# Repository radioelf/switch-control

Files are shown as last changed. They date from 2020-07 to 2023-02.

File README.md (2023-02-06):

# switch-control

switch-control/Crossover switch (Kicad Versión: 5.99.0, release build)

Interruptor, conmutador (doble), cruzamiento, controlado con un modulo ESP8266, lo estoy usando con Tasmota (https://github.com/arendst/Tasmota), con la siguiente configuración:
D2 GPIO4  Botón1in (126)
D1 GPIO5  Llave1n (82)
D6 GPIO12 Relé1 (21)
D7 GPIO13 Led1 (53)

Creative Commons License Disclaimer

UNLESS OTHERWISE MUTUALLY AGREED TO BY THE PARTIES IN WRITING, LICENSOR OFFERS THE WORK AS-IS AND MAKES NO REPRESENTATIONS OR WARRANTIES OF ANY KIND CONCERNING THE WORK, EXPRESS, IMPLIED, STATUTORY OR OTHERWISE, INCLUDING, WITHOUT LIMITATION, WARRANTIES OF TITLE, MERCHANTIBILITY, FITNESS FOR A PARTICULAR PURPOSE, NONINFRINGEMENT, OR THE ABSENCE OF LATENT OR OTHER DEFECTS, ACCURACY, OR THE PRESENCE OF ABSENCE OF ERRORS, WHETHER OR NOT DISCOVERABLE. SOME JURISDICTIONS DO NOT ALLOW THE EXCLUSION OF IMPLIED WARRANTIES, SO SUCH EXCLUSION MAY NOT APPLY TO YOU. EXCEPT TO THE EXTENT REQUIRED BY APPLICABLE LAW, IN NO EVENT WILL LICENSOR BE LIABLE TO YOU ON ANY LEGAL THEORY FOR ANY SPECIAL, INCIDENTAL, CONSEQUENTIAL, PUNITIVE OR EXEMPLARY DAMAGES ARISING OUT OF THIS LICENSE OR THE USE OF THE WORK, EVEN IF LICENSOR HAS BEEN ADVISED OF THE POSSIBILITY OF SUCH DAMAGES.

http://creativecommons.org/licenses/by-sa/3.0/

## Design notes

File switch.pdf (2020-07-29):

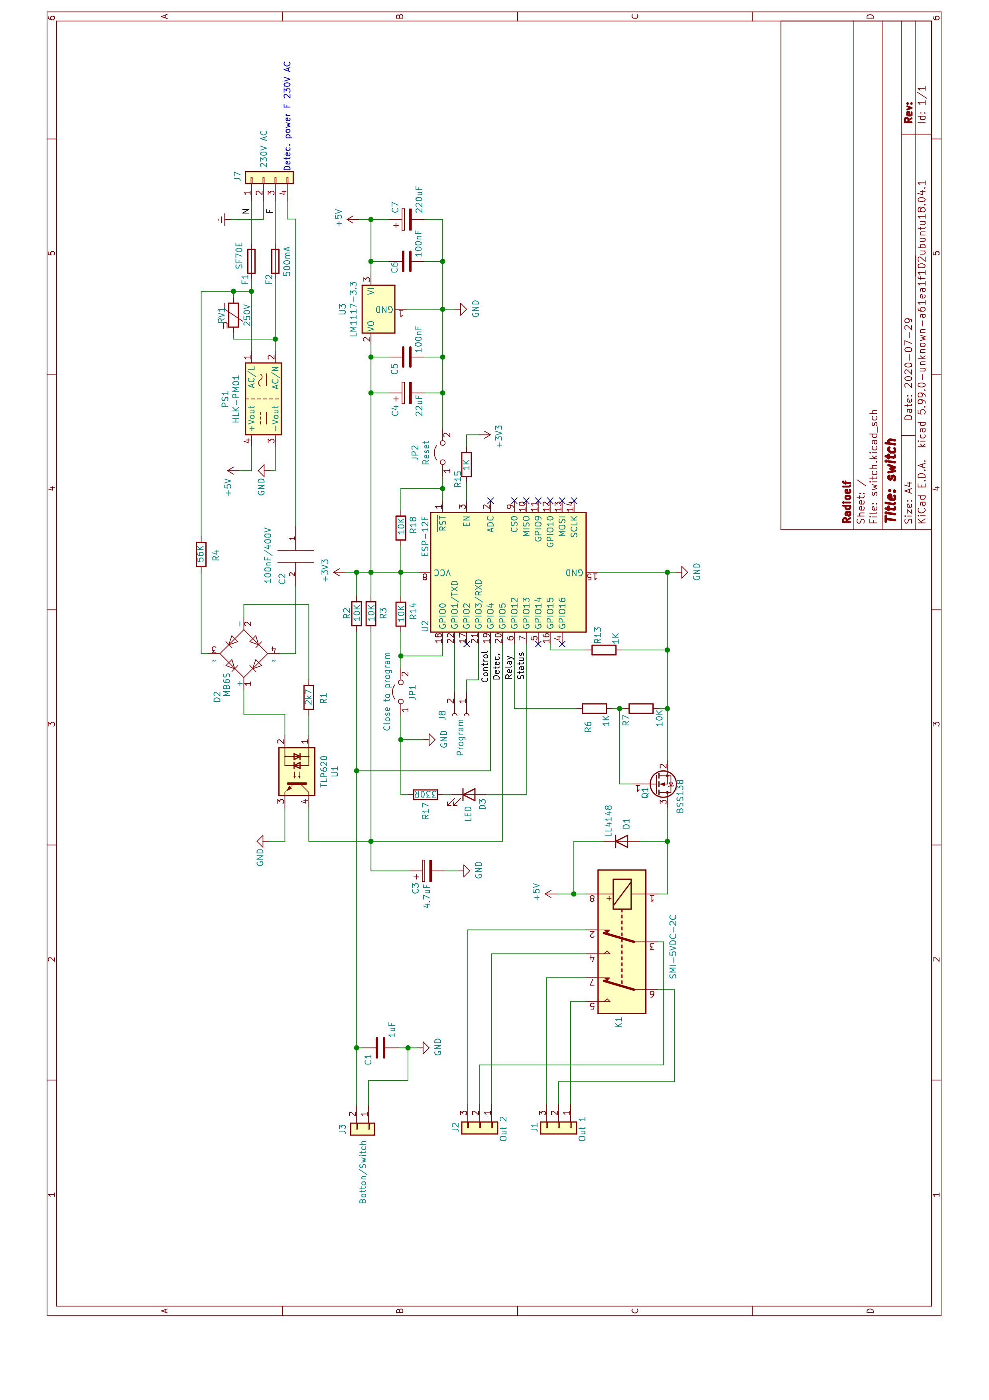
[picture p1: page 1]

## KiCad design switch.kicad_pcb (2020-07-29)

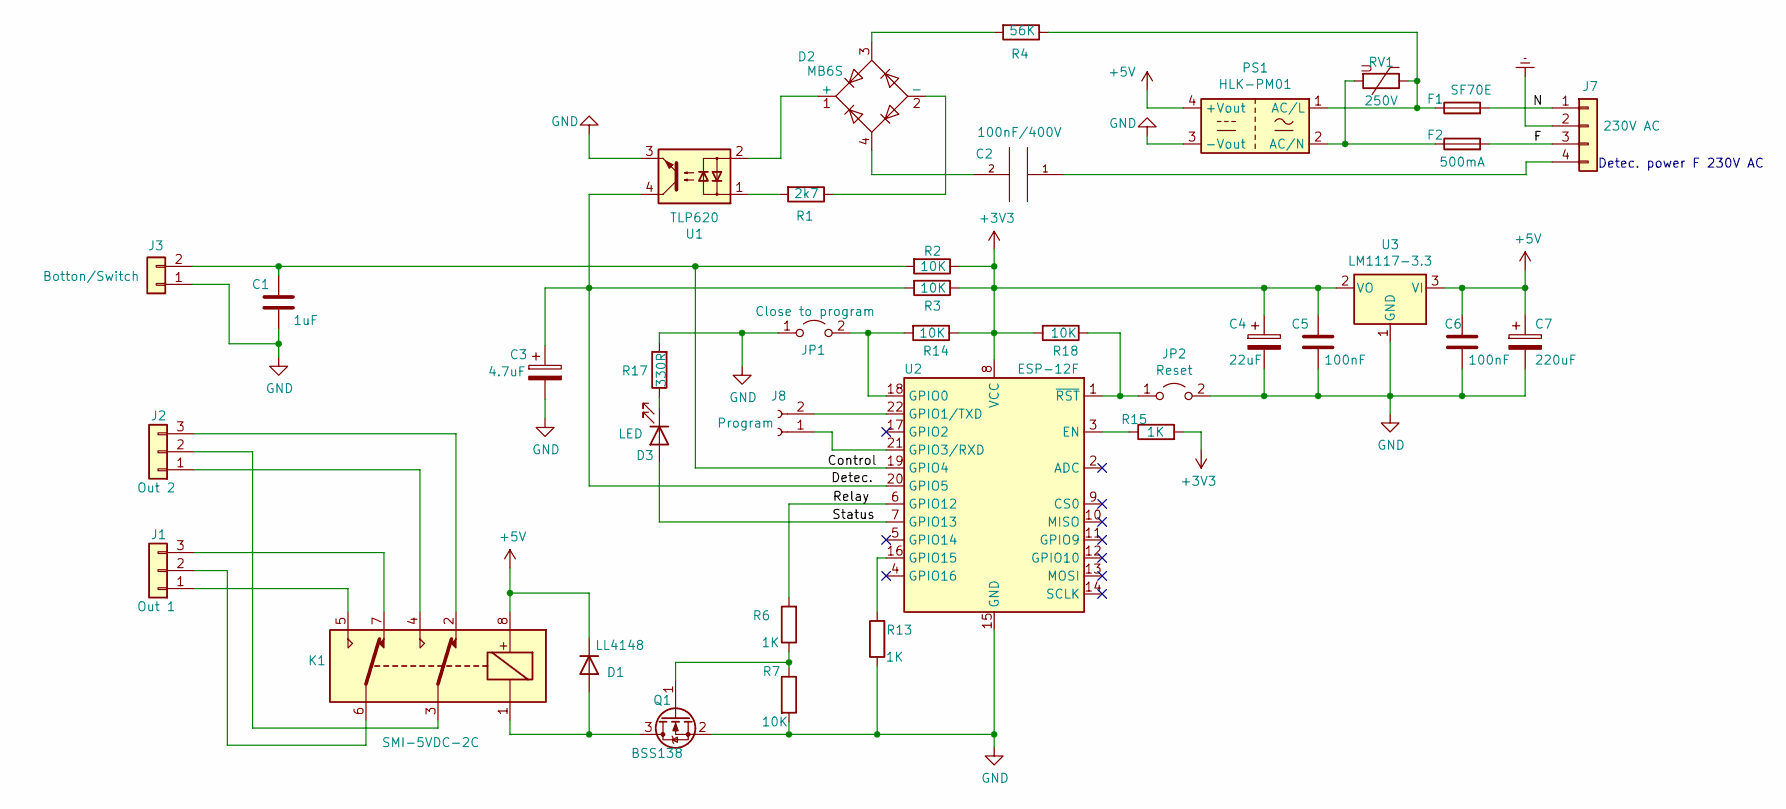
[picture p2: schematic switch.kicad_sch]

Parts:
C1: 1uF; C_1210_3225Metric
C2: 100nF/400V; C_Disc_D16.0mm_W5.0mm_P10.00mm
C3: 4.7uF; CP_Elec_4x3.9
C4: 22uF; CP_Elec_4x5.8
C5, C6: 100nF; L_0805_2012Metric_Pad1.15x1.40mm_HandSolder
C7: 220uF; CP_Elec_5x4.4
D1: LL4148; D_MiniMELF
D2: MB6S; TO-269AA
D3: LED; LED_0805_2012Metric
F1: SF70E; Fuse_Bourns_MF-RG400
F2: 500mA; R_Axial_DIN0207_L6.3mm_D2.5mm_P7.62mm_Horizontal
J1: Out 1; JST_NV_B03P-NV_1x03_P5.00mm_Vertical
J2: Out 2; JST_NV_B03P-NV_1x03_P5.00mm_Vertical
J3: Botton/Switch; JST_NV_B02P-NV_1x02_P5.00mm_Vertical
J7: 230V AC; JST_NV_B04P-NV_1x04_P5.00mm_Vertical
J8: Program; PinHeader_1x02_P2.54mm_Vertical
JP1: Close to program; PinHeader_1x02_P2.54mm_Vertical
JP2: Reset; PinHeader_1x02_P2.54mm_Vertical
K1: SMI-5VDC-2C; Relay_DPDT_Omron_G2RL
PS1: HLK-PM01; Converter_ACDC_HiLink_HLK-PMxx
Q1: BSS138; SOT-23
R1: 2k7; R_0805_2012Metric
R2, R3, R7, R14, R18: 10K; R_0805_2012Metric
R4: 56K; R_0805_2012Metric
R6, R13, R15: 1K; R_0805_2012Metric
R17: 330R; R_0805_2012Metric
RV1: 250V; RV_Disc_D12mm_W3.9mm_P7.5mm
U1: TLP620; DIP-4_W7.62mm_Socket_LongPads
U2: ESP-12F; ESP-12E
U3: LM1117-3.3; SOT-223-3_TabPin2

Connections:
+3V3: C4.1, C5.2, R2.1, R3.1, R14.1, R15.2, R18.2, U2.8 (VCC), U3.2 (VO)
+5V: C6.2, C7.1, D1.1 (K), K1.8, PS1.4 (+Vout), U3.3 (VI)
/Control: C1.2, J3.2, R2.2, U2.19 (GPIO4)
/F: F2.2, J7.3
/N: F1.2, J7.1
/Relay: R6.2, U2.6 (GPIO12)
/Status: D3.2 (A), U2.7 (GPIO13)
Earth: J7.2
GND: C1.1, C3.2, C4.2, C5.1, C6.1, C7.2, J3.1, JP1.1 (A), JP2.2 (B), PS1.3 (-Vout), Q1.2 (S), R7.2, R13.1, R17.2, U1.3, U2.15 (GND), U3.1 (GND)
unnamed: C2.1, J7.4
unnamed: C2.2, D2.4 (~~)
unnamed: C3.1, R3.2, U1.4, U2.20 (GPIO5)
unnamed: D1.2 (A), K1.1, Q1.3 (D)
unnamed: D2.1 (+), U1.2
unnamed: D2.2 (-), R1.1
unnamed: D2.3 (~~), R4.2
unnamed: D3.1 (K), R17.1
unnamed: F1.1, PS1.1 (AC/L), R4.1, RV1.1
unnamed: F2.1, PS1.2 (AC/N), RV1.2
unnamed: J1.1, K1.5
unnamed: J1.2, K1.6
unnamed: J1.3, K1.7
unnamed: J2.1, K1.4
unnamed: J2.2, K1.3
unnamed: J2.3, K1.2
unnamed: J8.1, U2.21 (GPIO3/RXD)
unnamed: J8.2, U2.22 (GPIO1/TXD)
unnamed: JP1.2 (B), R14.2, U2.18 (GPIO0)
unnamed: JP2.1 (A), R18.1, U2.1 (~RST)
unnamed: Q1.1 (G), R6.1, R7.1
unnamed: R1.2, U1.1
unnamed: R13.2, U2.16 (GPIO15)
unnamed: R15.1, U2.3 (EN)

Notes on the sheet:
Detec. power F 230V AC

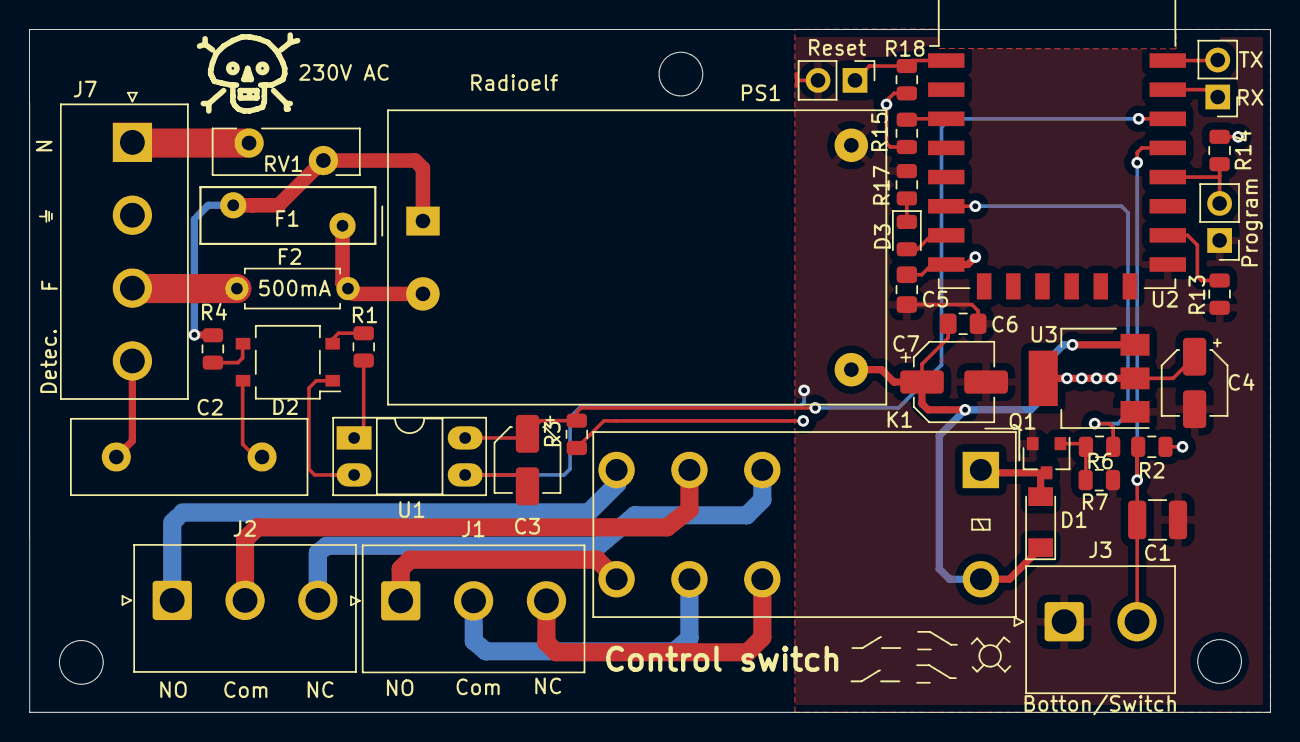
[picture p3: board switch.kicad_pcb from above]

Board: 2 copper layers, 85.2 x 46.9 mm, 37 parts (0 on the bottom side), 32 nets.
